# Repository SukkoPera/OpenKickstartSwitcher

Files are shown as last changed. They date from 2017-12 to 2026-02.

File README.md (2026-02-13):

# OpenKickstartSwitcher
OpenKickstartSwitcher is an Open Hardware Kickstart Switcher for Amiga Computers.

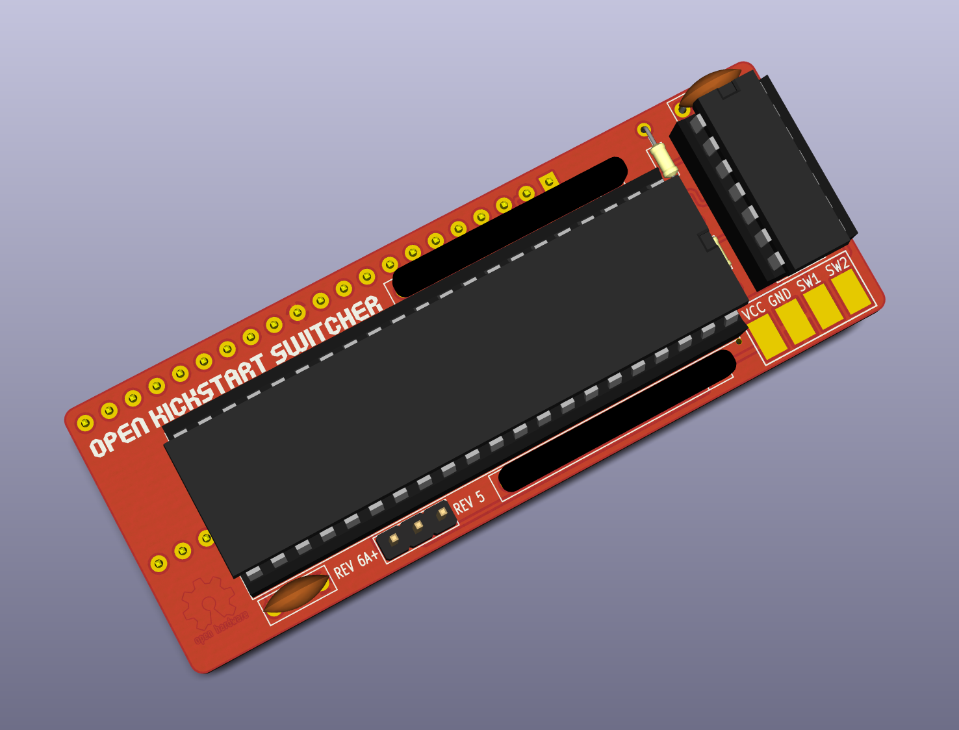
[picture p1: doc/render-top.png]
Board


### Summary
OpenKickstartSwitcher is a Kickstart switcher for Amiga computers, based on [work by Henryk Richter](http://bax.comlab.uni-rostock.de/en/hardware/amiga500/kickstart-eprom/). It allows switching among three or six different Kickstart images, stored in an EPROM. The switching can be done through physical switches or by pressing the mouse/joystick buttons at power-up. The latter requires [an external add-on board](https://github.com/SukkoPera/OpenAmigaMouseTrigger) that is another project of mine.

### Compatibility
The adapter is mostly targeted at Amiga 500+ users, who can use it to switch among Kickstart 3.1 (or 2.04 if they want to keep the version that came originally on their machines), 1.3 and maybe [a diagnostic ROM](http://www.diagrom.com), improving compatibility with older software that does not work correctly on Kickstart 2.x. Note that the adapter will have a tight fit on Rev.8A.1 mainboards (which is what 500+'s have): V2 was reworked to fix this issue, but the upper part of the shield will still touch the EPROM, so it is recommended to apply some insulation tape on the contact point or to remove the upper shield altogether (this won't do any harm, so don't worry too much about it, it will actually improve the internal cooling).

The situation is pretty much the same on Amiga 500s with Rev.6A mainboards.

Amiga 500 Rev.3 and 5 mainboards have their Kickstart sockets placed further towards the back of the machine, which allows the adapter to fit much better. There is plenty is space and you should manage to put everything in place and close the case properly. 

Besides the 500/500+, OpenKickstartSwitcher will work correctly on all Amiga models that have a single-chip Kickstart: this means it can be used on the A2000 just as well. It will also work on the A600, but you won't be able to place the keyboard back into the case, so it might be more useful when troubleshooting a broken mainboard. The same applies for the CDTV, but [a special version](https://github.com/SukkoPera/OpenKickstartSwitcherCDTV) was designed for this model, which will fit perfectly.

In all cases, **pay attention to put the revision selection jumper in the correct position**: one position is for A500 Rev.3 and 5, the other one is for all other cases, including A600 and A2000.

### Assembly
Solder all components to the board. No particular order is recommended, but starting with the smaller components might be a good idea.

The value of the two single resistors is not critical, 10k is recommended, but probably any value between 5k and 50k will do. If you intend on using 27C160 / 29F1615 with six images, you will need a pullup resistor of the same value between A19 and VCC; an 0805 SMD resistor fits in that space just fine. This is a tiny part, but it can be soldered without a loupe or microscope since the pads are pretty big.

My tests show that an SN74HC00 gate works fine. I don't recommend using parts from the *HC* series though, *HCT* or *LS* should be preferred.

The two resistor arrays are not always needed. First of all, these will end up in parallel to RP106 and RP107 on A500 boards, so you must skip them if those are already populated on your particular board. If they are not, you might still get away without them, depending on the particular EPROM you are using: I have several EPROMs of the same model (but different production batches), and some need the resistors while others don't, so the only way to find out is actual testing. For this I usually just load a Kickstart 1.2 disk, start up the four *Demos* and leave them running for a while. If the system does not hang/crash in like 15 minutes (usually it is much quicker than that, sometimes it even hangs before you can start all the demos!), you don't need them, otherwise you do. If you decide to install them, they must be of the *bussed* type and the recommended value is 4.7k. Be aware that these parts are polarized and must be installed in a certain verse!

### EPROM Selection and Switch Wiring
Since V2, the adapter can be used with either 27C800 or 27C160 EPROMs (earlier versions only supported the former). I recommend using *-100F1* EPROMs by ST, but access time is not critical: use 100ns or faster EPROMs if you can, but anything up to 150ns should work reliably. If you do not have a UV eraser, you may use an MX29F1615 DIP42 chip which is a direct, pin compatible replacement of 27C160.

#### 27C800
With a 27C800 EPROM, the adapter supports 2x256 KB Kickstart images (i.e.: up to version 1.3) and 1x512 KB image (version 2 and later).

To switch between ROMs, you will need two SPDT switches, connected to the SW1/SW2 pads and ground. A ground pad is available on the board, but any ground spot on the mainboard can be used as well, if easier to reach.

| ROM Image # | Size (KB) | SW1 | SW2 |
|---|---|-----|-----|
| 1 | 256 | LOW | LOW |
| 2 | 256 | HIGH| LOW |
| 3 | 512 |  x  | HIGH|

(x = Don't Care)

So, basically:
* If SW2 is HIGH, the 512 KB Kickstart image is selected, regardless of SW1.
* If SW2 is LOW, SW1 controls which one of the two 256 KB images is enabled: LOW selects the first one, and HIGH selects the second one.

You can also use a single ON-OFF-ON DPDT switch, just wire ground to the middle pins, SW1 and SW2 on one side and SW2 on the other.

As SW1/SW2 will both read as HIGH if left unconnected, the 512 KB Kickstart will be selected if no switches are wired.

You can fully ignore the A19 pad on the bottom side of the board, when using a 27C800 EPROM.

#### 27C160 / 29F1615
With a 27C160 EPROM, the adapter supports up to 4x256 KB Kickstart images and 2x512 KB images.

You will need to solder an additional switch to the A19 pad on the bottom side of the board. VCC and GND pads are provided nearby so that you can also solder a pull-up/down resistor.

If you want to keep using a single switch, an eight position BCD coded rotary switch is an option. In your BCD switch's documentation, pins are going to be called 1, 2, 4, and C (collect). Wire collect to GND, SW1 to pin called 1, SW2 to pin 2, and A19 to pin 4; remember about the pullup resistor between A19 and VCC! This will result in a switch that goes "backwards": first image from your EPROM will be on switch position number 7. 512k images take two switch positions (0-1 and 4-5).

| ROM Image # | Size (KB) | SW1 | SW2 | A19 |
|---|---|-----|-----|-----|
| 1 | 256 | LOW | LOW | LOW |
| 2 | 256 | HIGH| LOW | LOW |
| 3 | 512 |  x  | HIGH| LOW |
| 4 | 256 | LOW | LOW | HIGH|
| 5 | 256 | HIGH| LOW | HIGH|
| 6 | 512 |  x  | HIGH| HIGH|

**IMPORTANT: ALWAYS TURN YOUR AMIGA OFF BEFORE MOVING THE SELECTION SWITCHES!**

#### Flashing Notes
When flashing the EPROM, make sure that the ROM images you are using are exactly 262144 or 524288 bytes long, and just concatenate them. Take care to use the correct byte ordering, as the Amiga hardware expects 16-bit words to be stored in the *big-endian* format (which is NOT the format UAE expects them in, for the record). On Unix-like systems you can use the *conv=swab* option of *dd* to change the byte ordering.

27C800s and 27C160 are 42-pin EPROMs and most programmers only support chips up to 40 pins. This is the case with [the popular TL866 programmer](http://autoelectric.cn/EN/TL866_main.html), for instance. You can get around this limitation with an adapter PCB. There are at least two open designs of such an adapter:
* [One by keirff](https://github.com/keirf/PCB-Projects) (who, interestingly, has his own Kickstart Switcher)
* [And another one by gaggi](https://github.com/gaggi/27c160-tl866-adapter)

I have only used the latter and found it to be working fine. 

The above adapters *should* work with MX29F1615, but this has not been confirmed; the official ADP_D42_EX-A for the T48 programmer is confirmed working with them.

### Installation
Once your OpenKickstartSwitcher is assembled and programmed, the rest of the installation should be pretty straightforward:
* Open your Amiga.
* Remove the shielding.
* Set the revision selection jumper on OpenKickstartSwitcher according to the Amiga model (see above). On Amiga 500/500+'s you can identify the mainboard revision by looking at the bottom right corner near the floppy drive zone.
* Identify the Kickstart chip.
* Carefully remove it.
* Plug OpenKickstartSwitcher in its place, making sure to match the correct orientation.
* Drill two holes into the back of your Amiga (or wherever you prefer) and screw two switches in there.
* Solder wires to switches.
* Replace your shielding.
* Close your Amiga.

Of course, if you use OpenAmigaMouseTrigger there is no need to drill any holes.

### DiagROM
The excellent [DiagROM by chucky](http://www.diagrom.com) can be used with OpenKickstartSwitcher.

Normally it is distributed as a 512 KB image, but most of the space is unused, so I have created a 256 KB version of DiagROM 1.0 by simply truncating the image. It is **NOT GUARANTEED TO WORK**, but it looks fine to me. It can be [downloaded here](https://github.com/SukkoPera/OpenKickstartSwitcher/files/1777856/diagrom-256k.zip).

### License
OpenKickstartSwitcher is Open Hardware. If you make any modifications to the board, please contribute them back.

### Support the Project
Since the project is open you are free to get the PCBs made by your preferred manufacturer, however in case you want to support the development, you can order them from PCBWay through this link:

PCB from PCBWay (https://www.pcbway.com/project/shareproject/OpenKickstartSwitcher_V2.html)

You get cheap, professionally-made and good quality PCBs, I get some credit that will help with this and [other projects](https://www.pcbway.com/project/member/shareproject/?bmbid=41100). You won't even have to worry about the various PCB options, it's all pre-configured for you!

Also, if you still have to register to that site, [you can use this link](https://www.pcbway.com/setinvite.aspx?inviteid=41100) to get some bonus initial credit (and yield me some more).

Again, if you want to use another manufacturer, feel free to, don't feel obligated :). But then you can buy me a coffee if you want:



### Thanks
Thanks to Henryk Richter and the guys at the Italian Amiga Page forum.
Kudos to Aldo PRS for prividing information about how the adapter fits on the various A500/500+ mainboard revisions.

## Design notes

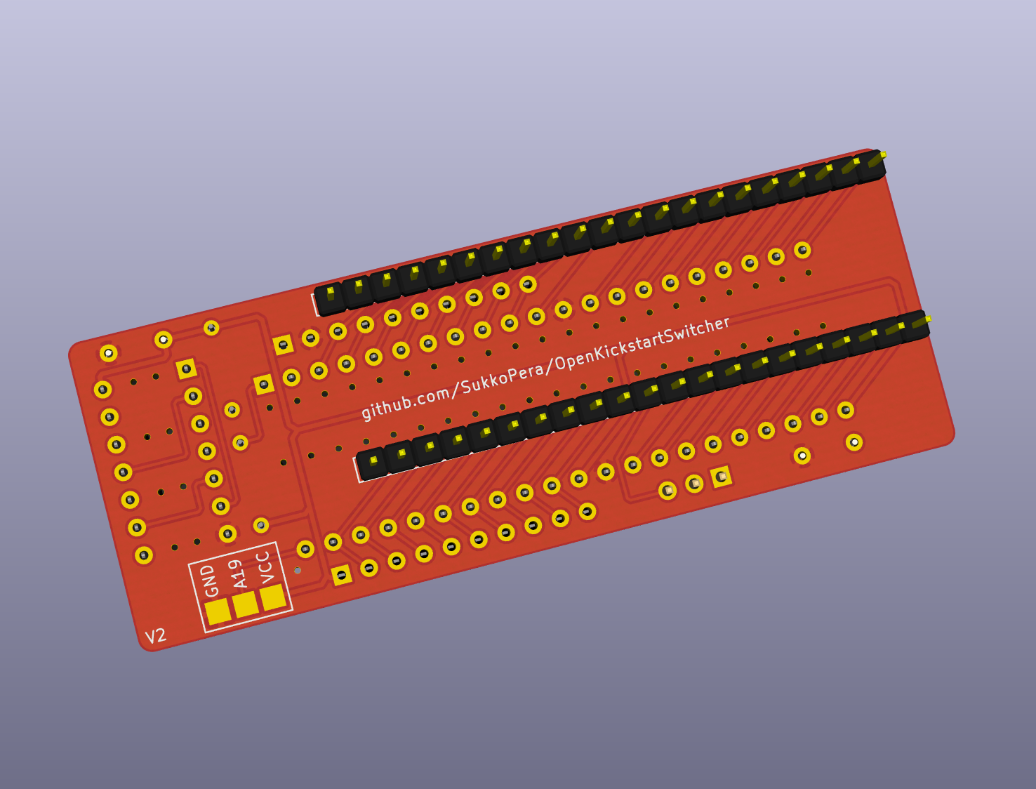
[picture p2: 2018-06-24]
doc/render-bottom.png

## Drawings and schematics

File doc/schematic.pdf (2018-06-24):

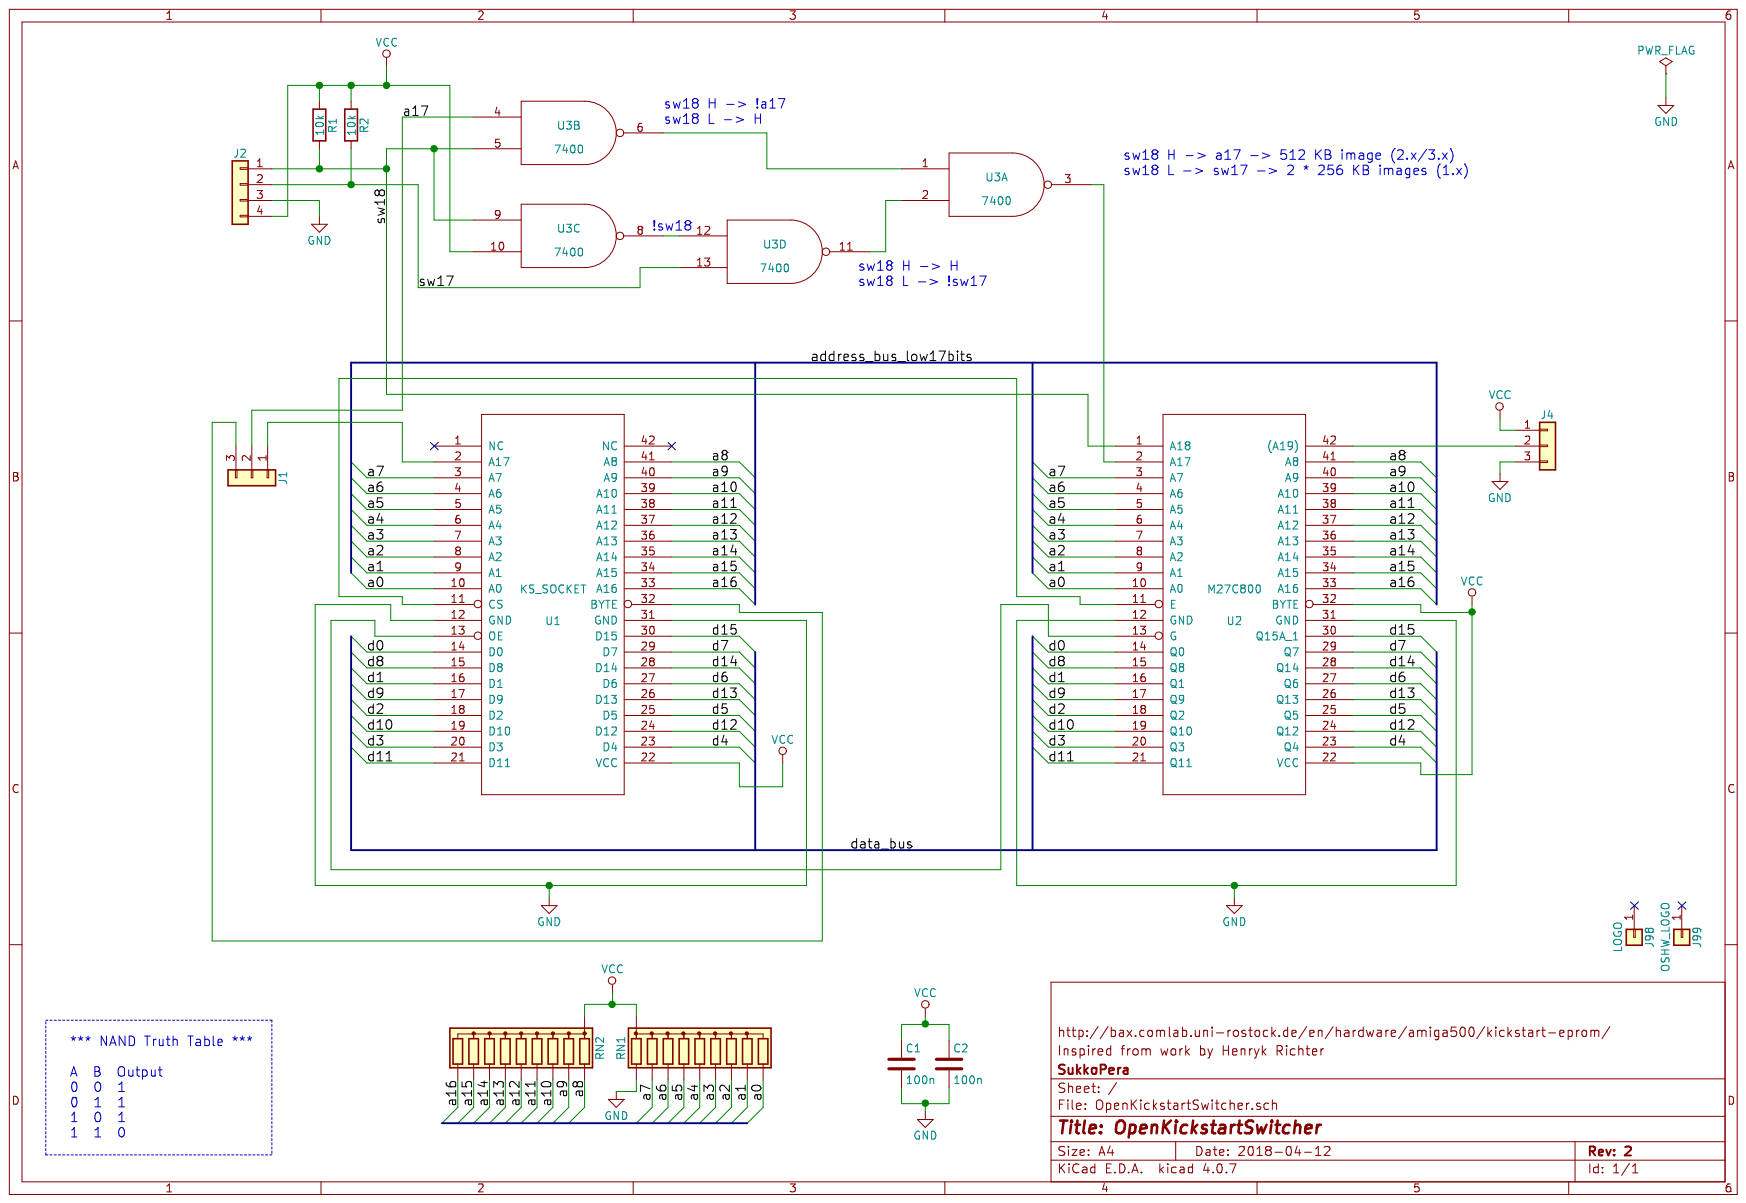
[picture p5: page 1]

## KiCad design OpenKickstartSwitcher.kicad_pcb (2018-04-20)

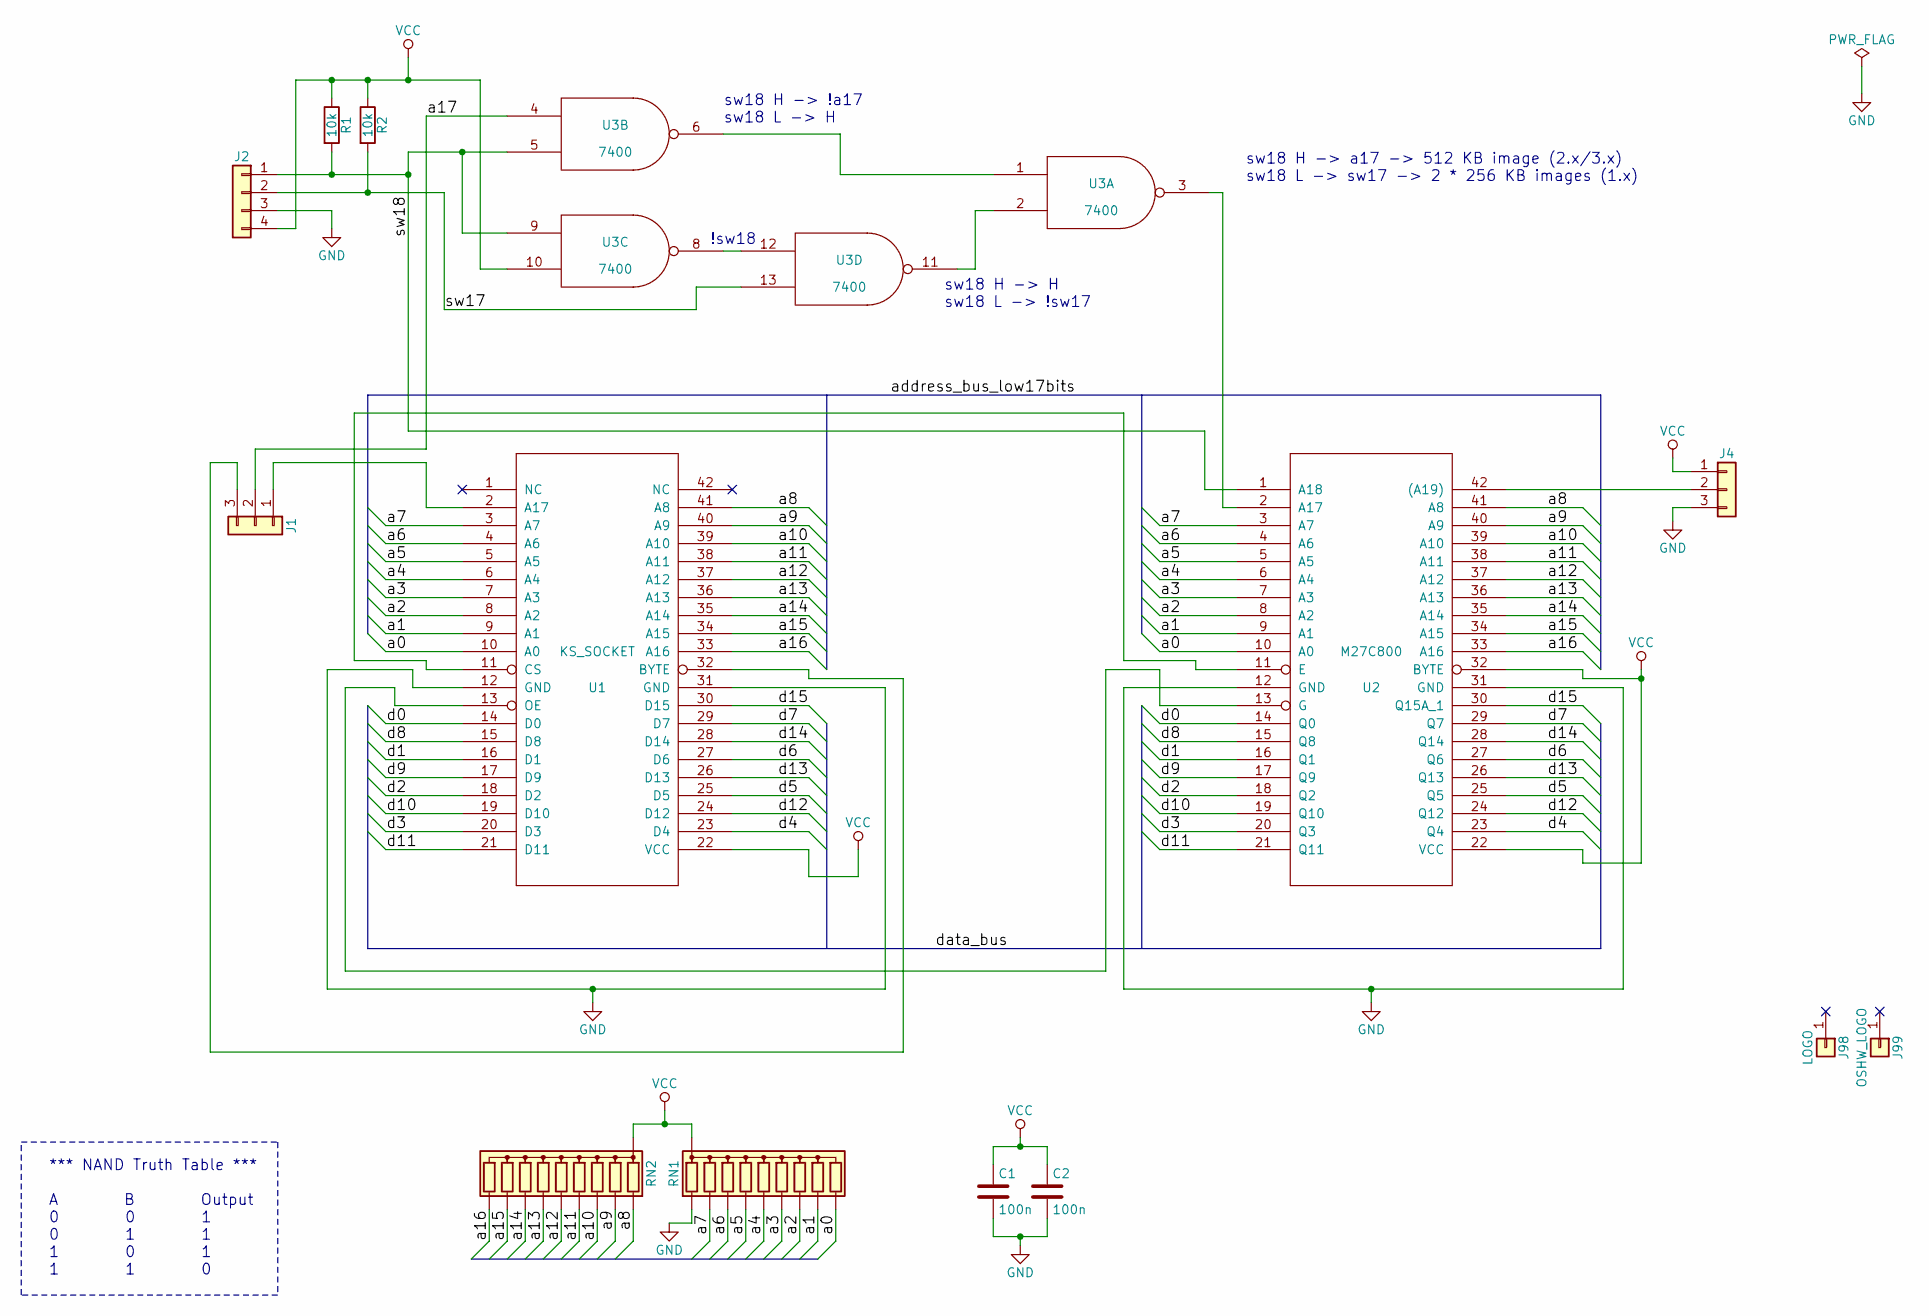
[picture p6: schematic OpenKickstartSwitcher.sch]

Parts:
C1, C2: 100n; C_Disc_D7.0mm_W2.5mm_P5.00mm
J1: Conn_01x03; Pin_Header_Straight_1x03-ModSilkS
J2: Conn_01x04; LoosePads-4
J4: Conn_01x03; SolderJumper
J98: LOGO; logo
J99: OSHW_LOGO; Logo_copper_OSHW_6x6mm
R1, R2: 10k; R_Axial_DIN0204_L3.6mm_D1.6mm_P7.62mm_Horizontal
RN1, RN2: 4.7k; R_Array_SIP10
U1: KS_SOCKET; DIP-42_DualHeaderStrips
U2: M27C800; DIP-42_Socket
U3: 7400; DIP-14_W7.62mm

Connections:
/a0: RN1.10 (R9), U1.10 (A0), U2.10 (A0)
/a1: RN1.9 (R8), U1.9 (A1), U2.9 (A1)
/a2: RN1.8 (R7), U1.8 (A2), U2.8 (A2)
/a3: RN1.7 (R6), U1.7 (A3), U2.7 (A3)
/a4: RN1.6 (R5), U1.6 (A4), U2.6 (A4)
/a5: RN1.5 (R4), U1.5 (A5), U2.5 (A5)
/a6: RN1.4 (R3), U1.4 (A6), U2.4 (A6)
/a7: RN1.3 (R2), U1.3 (A7), U2.3 (A7)
/a8: RN2.2 (R1), U1.41 (A8), U2.41 (A8)
/a9: RN2.3 (R2), U1.40 (A9), U2.40 (A9)
/a10: RN2.4 (R3), U1.39 (A10), U2.39 (A10)
/a11: RN2.5 (R4), U1.38 (A11), U2.38 (A11)
/a12: RN2.6 (R5), U1.37 (A12), U2.37 (A12)
/a13: RN2.7 (R6), U1.36 (A13), U2.36 (A13)
/a14: RN2.8 (R7), U1.35 (A14), U2.35 (A14)
/a15: RN2.9 (R8), U1.34 (A15), U2.34 (A15)
/a16: RN2.10 (R9), U1.33 (A16), U2.33 (A16)
/a17: J1.2, U3.4
/d0: U1.14 (D0), U2.14 (Q0)
/d1: U1.16 (D1), U2.16 (Q1)
/d2: U1.18 (D2), U2.18 (Q2)
/d3: U1.20 (D3), U2.20 (Q3)
/d4: U1.23 (D4), U2.23 (Q4)
/d5: U1.25 (D5), U2.25 (Q5)
/d6: U1.27 (D6), U2.27 (Q6)
/d7: U1.29 (D7), U2.29 (Q7)
/d8: U1.15 (D8), U2.15 (Q8)
/d9: U1.17 (D9), U2.17 (Q9)
/d10: U1.19 (D10), U2.19 (Q10)
/d11: U1.21 (D11), U2.21 (Q11)
/d12: U1.24 (D12), U2.24 (Q12)
/d13: U1.26 (D13), U2.26 (Q13)
/d14: U1.28 (D14), U2.28 (Q14)
/d15: U1.30 (D15), U2.30 (Q15A_1)
/sw17: J2.2, R2.2, U3.13
/sw18: J2.1, R1.2, U2.1 (A18), U3.5, U3.9
GND: C1.2, C2.2, J2.3, J4.3, RN1.2 (R1), U1.12 (GND), U1.31 (GND), U2.12 (GND), U2.31 (GND), U3.7 (GND)
unnamed: J1.1, U1.2 (A17)
unnamed: J1.3, U1.32 (BYTE)
unnamed: J4.2, U2.42 ((A19))
unnamed: U1.11 (CS), U2.11 (E)
unnamed: U1.13 (OE), U2.13 (G)
unnamed: U2.2 (A17), U3.3
unnamed: U3.1, U3.6
unnamed: U3.2, U3.11
unnamed: U3.8, U3.12
VCC: C1.1, C2.1, J2.4, J4.1, R1.1, R2.1, RN1.1 (common), RN2.1 (common), U1.22 (VCC), U2.22 (VCC), U2.32 (BYTE), U3.10, U3.14 (VCC)

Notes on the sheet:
sw18 H -> a17 -> 512 KB image (2.x/3.x) sw18 L -> sw17 -> 2 * 256 KB images (1.x)
!sw18
sw18 H -> !a17 sw18 L -> H
sw18 H -> H sw18 L -> !sw17
*** NAND Truth Table *** A B Output 0 0 1 0 1 1 1 0 1 1 1 0

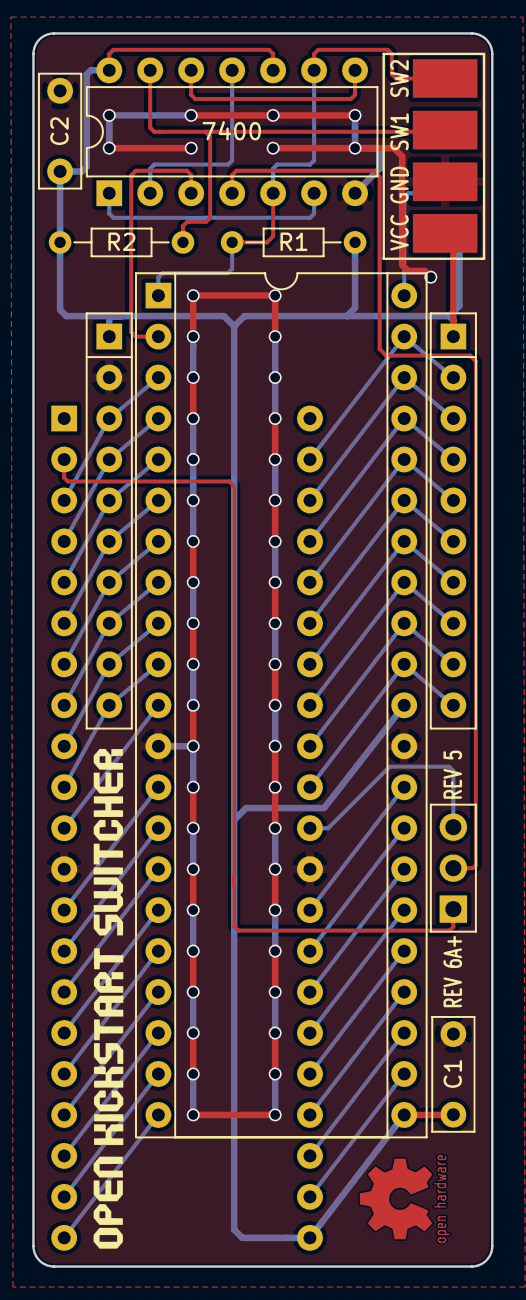
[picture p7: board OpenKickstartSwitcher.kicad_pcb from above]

Board: 2 copper layers, 28.4 x 76.5 mm, 14 parts (1 on the bottom side), 47 nets.

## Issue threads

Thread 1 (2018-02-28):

2MB Version

rmueller83, 2018-02-28:
Hi,

could you also design a 2MB version? It would be nice to have a >2.0 Kickstart and additionally [DiagROM](http://www.diagrom.com/index.php/download/) which also needs 512KiB.

SukkoPera, 2018-03-03:
Try this, it's DiagROM 1.0 16-bit version reduced to a 256Kb file. Needs to be byteswapped when burning to an actual EPROM.

[diagrom-256k.bin.zip](https://github.com/SukkoPera/OpenKickstartSwitcher/files/1777851/diagrom-256k.bin.zip)

SukkoPera, 2018-03-13:
Also tested on a couple of real Amigas, works well!

SukkoPera, 2018-06-24:
V2, just released, exposes A19 when using a M27C160 EPROM and allows up to 6 Kickstarts: 4x256KB + 2x512KB.

https://github.com/SukkoPera/OpenKickstartSwitcher/releases/tag/v2

rmueller83, 2018-06-25:
Thank you, that's great news! I made 3 orders of M27C800 EPROMs (15 EPROMs in total) from China, but none of them works with the widespread MiniPro TL866 programmer and KeirF adaptor. :-( The M27C160 works fine with another switcher.

SukkoPera, 2018-06-25:
That's weird, I use a TL866CS with Keirf's adapter and the M27C800s I ordered from China all work fine. Maybe they need to be erased first?

The same configuration also works with M27C160s.

jingsno, 2018-08-18:
Thanks for designing the PCB, and making it available! Did you use any special tools to make the 256KB version of DiagROM, or just chop of the last 256KBs? Looks like your version has a few extra instructions right at the end of the 256KB address space, some jump instructions maybe? I'd like to flash the latest version of Diagrom, as it has some Zorro III fixes.

SukkoPera, 2018-08-19:
Not really, I created it by hand. I guess I could come up with some Linux commands to make it, but I actually think that the 16-bit version of Diagrom should be a 256K file from the start.

Anyway, the version linked above is the latest one as far as I know, why do you think there's a later one?

SukkoPera, 2018-08-19:
I have been examinating the latest daily release and I think you can just truncate the ROM at 256k.

I also saw it has a new checksum feature, which will fail, but the ROM should work well anyway, as there's nothing in the part that gets truncated. Actually, at offset 0x21C80 (which comes way before the truncation point), the ROM contains the following message:

    This is the brutal end of this ROM, everything after this are just pure noise.    End of Code

Closed 2018-06-24.

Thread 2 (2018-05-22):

Switcher don´t fit between Mainboard and Keyboard

Konstantin19, 2018-05-22:
There is not enough space between mainboard and keyboard. You have to make an offset of the eprom with at least 5 pins to the back. But there is a capacitor so that this is not a good idea. Whats about to put a 40 pin (2x20) header to use an IDE HDD flat cable in combination with a IC socket connector?

Tested on Amiga 500 Rev.8a.1

Technically working 100% with Kick 1.3 / Kick 3.1 / Diag ROM

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

SukkoPera, 2018-05-22:
That's already been taken care of in V2. I received the prototypes last Saturday and tested them yesterday, the situation improves a lot. I will release V2 ASAP.

SukkoPera, 2018-05-22:
https://www.dropbox.com/s/jv2uiiooumskxhr/Foto%2019-05-18%2C%2018%2028%2018.jpg?dl=0&raw=1

Kalidomra, 2018-06-24:
Any ETA on V2?

SukkoPera, 2018-06-24:
Tests completed this morning. It's now released:

https://github.com/SukkoPera/OpenKickstartSwitcher/releases/tag/v2

Closed 2018-06-24.

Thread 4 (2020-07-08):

Mechanical incompatibility between OpenKickstartSwitcher and OpenAmiga600FastRamExpansion

TzOk83, 2020-07-08:
I had a really hard time putting together the OpenKickstartSwitcher and the OpenAmiga600FastRamExpansion in my Amiga 600. They do fit, but I had to cut a corner of the OKS board, which collides with the CPLD socket (this part has no tracks, just the Open Hardware logo). I have also had to cut all the excessive parts of pins from the resistor array and goldpins, and put some kapton tape for the insulation. If the EPROM is soldered onto the board it fits under the keyboard and it is (barely) possible to close the A600 case.

SukkoPera, 2020-07-08:
I'm sorry, but as the README states, this project is mainly targeted at the A500, it won't fit cleanly in an A600 even by itself, and I'm sure the RAM card makes things even worse.

I'm going to mark this as "help needed" and leave it open, in case anyone wants to reshape the board so that it fits better in the A600 (schematics are already OK).

TzOk83, 2020-07-09:
It actually fits the A600 fine, but you can't use sockets under ICs, and you have to trim the goldpin pins about 2 mm, so the connector fits the EPROM socket on the motherboard without any gap.

lovrenco, 2020-10-15:
I was thinking of getting this for Amiga600 among with Chipram and Fastram expansion, and now I read it will notfit?
Uh, what I mean is, Amiga 600 is ideal computer for casual gaming, since it takes up very little space unlike Amiga 500.
If you ad Gotek with FlashFloppy to it, using this kickstart switcher you could have best of both worlds:
1. With kick 1.3 great compatibility wit ADF-s
2. With Kick 3 and above great support for Whdload games library on big SD card.

Is there a way to put all 3 addons to Amiga 600?

TzOk83, 2020-10-15:
For 2 ROMs you just need to pull 1 "leg" of 27C800 out of socket, and wire a switch to it. As KS1.3 is only 256kB, you need to put it twice.

However, this switcher will fit A600 if you solder EPROM directly to it or solder the switcher board directly to the mainboard, and don't have the top shield (v1.5 and newer units didn't have it from factory).

SukkoPera, 2020-10-15:
> I was thinking of getting this for Amiga600 among with Chipram and Fastram expansion, and now I read it will notfit?

This is stated pretty clearly in the README:

> It will also work on the A600, but you won't be able to place the keyboard back into the case

And yeah. the A600 is small, that's exactly why fitting expansions into it is so problematic.

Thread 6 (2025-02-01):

Suggestion: Add a diferent switch option in README

shindouj, 2025-02-01:
Hi! First of all - thank you SO MUCH for your awesome contributions to the Amiga world, especially the big ones, like the Raemixx500.

When I was sourcing items for the Kickstart switcher I have learnt about the existence of binary code switches, like [these cheap ones from China](https://www.aliexpress.com/item/1005004047981126.html?utparam-url=scene%3Asearch%7Cquery_from%3A) and I find them the perfect pick for somebody who's not opposed to drilling a hole in their case (my case was drilled by the previous owner, so no tears were shed over that choice!). They allow switching through a set number of digits, I have picked the 0-7 one as I am using all six images.

Wiring is painfully simple too: SW1 went to pin 1 on the switch, SW2 to pin 2, A19 to pin 4, GND to collect, and I have added a 10k 0805 pullup between VCC and A19. This gets the switch to go "backwards": the last ROM from the EPROM is on numbers 0 and 1 (as it is a 512k), and the first one is on number 7. Additional benefit of these switches is that there are versions requiring a screwdriver to be turned, making accidental switches during the operation impossible.

Would you be inclined to mention that option in the README? I think it would be very beneficial for future users - at least for me having this one was a no-brainer in comparison to having two separate switches.

Additionally, one other thing that could be mentioned is the potential of using MX29F1615 flash chips instead of 27c160 EPROMs - these MX chips are pretty widely available and electrically erasable, being a much friendlier option for amateurs without UV erasers like myself.

If you are okay with making these changes, I would be more than happy to make a PR. Thanks!

SukkoPera, 2025-02-02:
Hi, thanks for enthusiasm, I wish there were more people like you. I'll be brutally honest: the Amiga "community" has pis*ed me off so much that I will never ever move a single finger for the Amiga scene again.

However, if all it takes is accept a pull request, I will do that, so feel free to submit it.

shindouj, 2025-02-02:
I have seen parts of these disputes and I am sorry you have not gotten the recognition you deserved. Without people like you, EmberHeavyIndustries, jbilander and jm27 my Amiga would cost twice as much and I would learn nothing about electronics; this way I got to learn how to microsolder, solve issues with electronics, and vastly expand my workshop. Being able to build all my Amiga utilities myself was very important indeed.

I have submitted the PR your way, feel free to merge it whenever it suits you.

SukkoPera, 2025-02-03:
TBH it's not about recognition, it's more about understanding what really helps the scene in the long term and what doesn't. It's about giving back rather than just taking. It's about creating an ecosystem that will allow Amiga to survive past the immediate future. None of the retro scenes shine particularly about these points, but the Amiga one is just _terrible_ at all of them.

Anyway, forgive the rant and thanks for your contribution, merged!

Closed 2025-02-03.

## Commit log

2017-12-15 Fix EPROM footprint
    [OpenKickstartSwitcher.kicad_pcb, OpenKickstartSwitcher.sch]
2017-12-15 Add OSHW logo and URL
    [OpenKickstartSwitcher.kicad_pcb, OpenKickstartSwitcher.sch]
2017-12-15 Move logo/URL slightly
    [OpenKickstartSwitcher.kicad_pcb]
2017-12-15 Slight corner fixes
    [OpenKickstartSwitcher.kicad_pcb]
2017-12-15 Added capacitor, more space for resistors and minor adjustments
    [OpenKickstartSwitcher.kicad_pcb, OpenKickstartSwitcher.sch]
2017-12-17 Add capacitor on 7400 I don't like this too much, tracks under the 7400 are pretty messy. Let's see if we can come up with something better.
    [OpenKickstartSwitcher.kicad_pcb, OpenKickstartSwitcher.sch]
2017-12-18 Much better now :)
    [OpenKickstartSwitcher.kicad_pcb, OpenKickstartSwitcher.sch]
2017-12-18 Re-add OSHW logo
    [OpenKickstartSwitcher.kicad_pcb]
2017-12-18 Minor routing adjustments
    [OpenKickstartSwitcher.kicad_pcb]
2017-12-22 Add logo and improve ground stitching
    [OpenKickstartSwitcher.kicad_pcb]
2018-01-07 Final touches for V1
    [OpenKickstartSwitcher.kicad_pcb, OpenKickstartSwitcher.sch]
2018-04-10 Fix form factor for a better fit in A500's
    [OpenKickstartSwitcher.kicad_pcb]
2018-04-10 Almost ready for V2
    [OpenKickstartSwitcher.kicad_pcb, OpenKickstartSwitcher.sch]
2018-04-10 Minor fixes
    [OpenKickstartSwitcher.kicad_pcb]
2018-04-10 Make logo larger
    [OpenKickstartSwitcher.kicad_pcb]
2018-04-10 Use smaller footprint for resistors
    [OpenKickstartSwitcher.kicad_pcb, OpenKickstartSwitcher.sch]
2018-04-12 Routing improvements
    [OpenKickstartSwitcher.kicad_pcb]
2018-04-12 Replace SW3 with a solder jumper
    [OpenKickstartSwitcher.kicad_pcb, OpenKickstartSwitcher.sch]
2018-04-20 Minor adjustments
    [OpenKickstartSwitcher.kicad_pcb]
2018-06-24 Update renders and schematics PDF
2025-02-02 Added info about MX29F1615 and BCD switches
    Addresses #6
